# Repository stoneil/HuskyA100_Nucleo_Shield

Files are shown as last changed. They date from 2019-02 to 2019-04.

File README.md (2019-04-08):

Husky A100 Nucleo Shield
===

## Circuit

This board is for my MQP (Major Qualifying Project) to develop a autonomous robotic platform to compete in the Intelligent Ground Vehicle Competition. The purpose of this board is to provide a secure connection between the STM32F7 Nucleo microcontroller board, the Talon motor controllers (PWM) and the US Digital quadrature encoders. It breaks out power and I/O to all the connectors.

## PCB Layout
v1.0
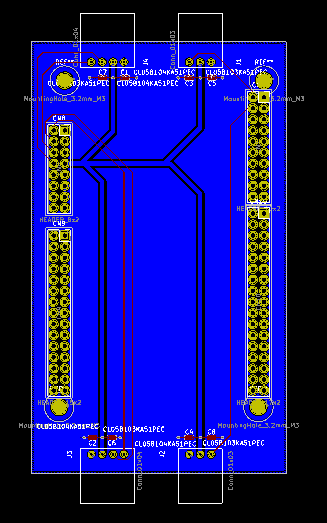
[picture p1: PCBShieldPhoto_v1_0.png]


v1.2
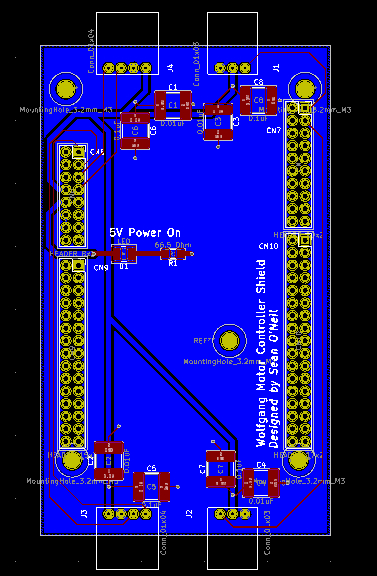
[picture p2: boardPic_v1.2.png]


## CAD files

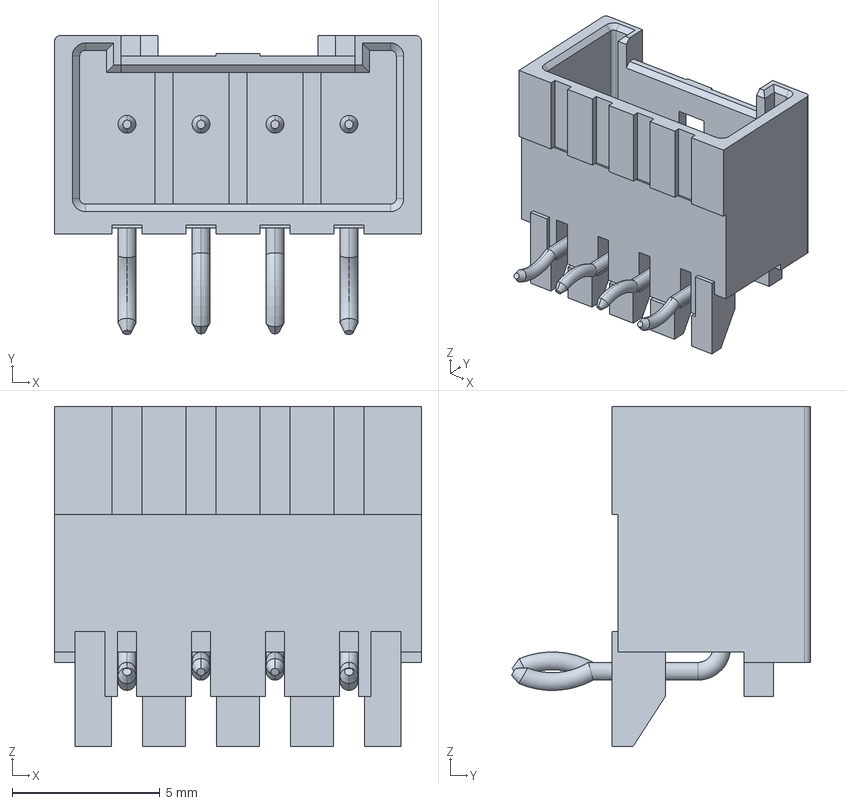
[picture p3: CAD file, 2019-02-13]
Custom_Project_Libraries/Molex_Mini-Lock.shapes/Molex Mini-Lock Horizontal Header 4 circuit.stp
12.4 x 10.1 x 11.5 mm

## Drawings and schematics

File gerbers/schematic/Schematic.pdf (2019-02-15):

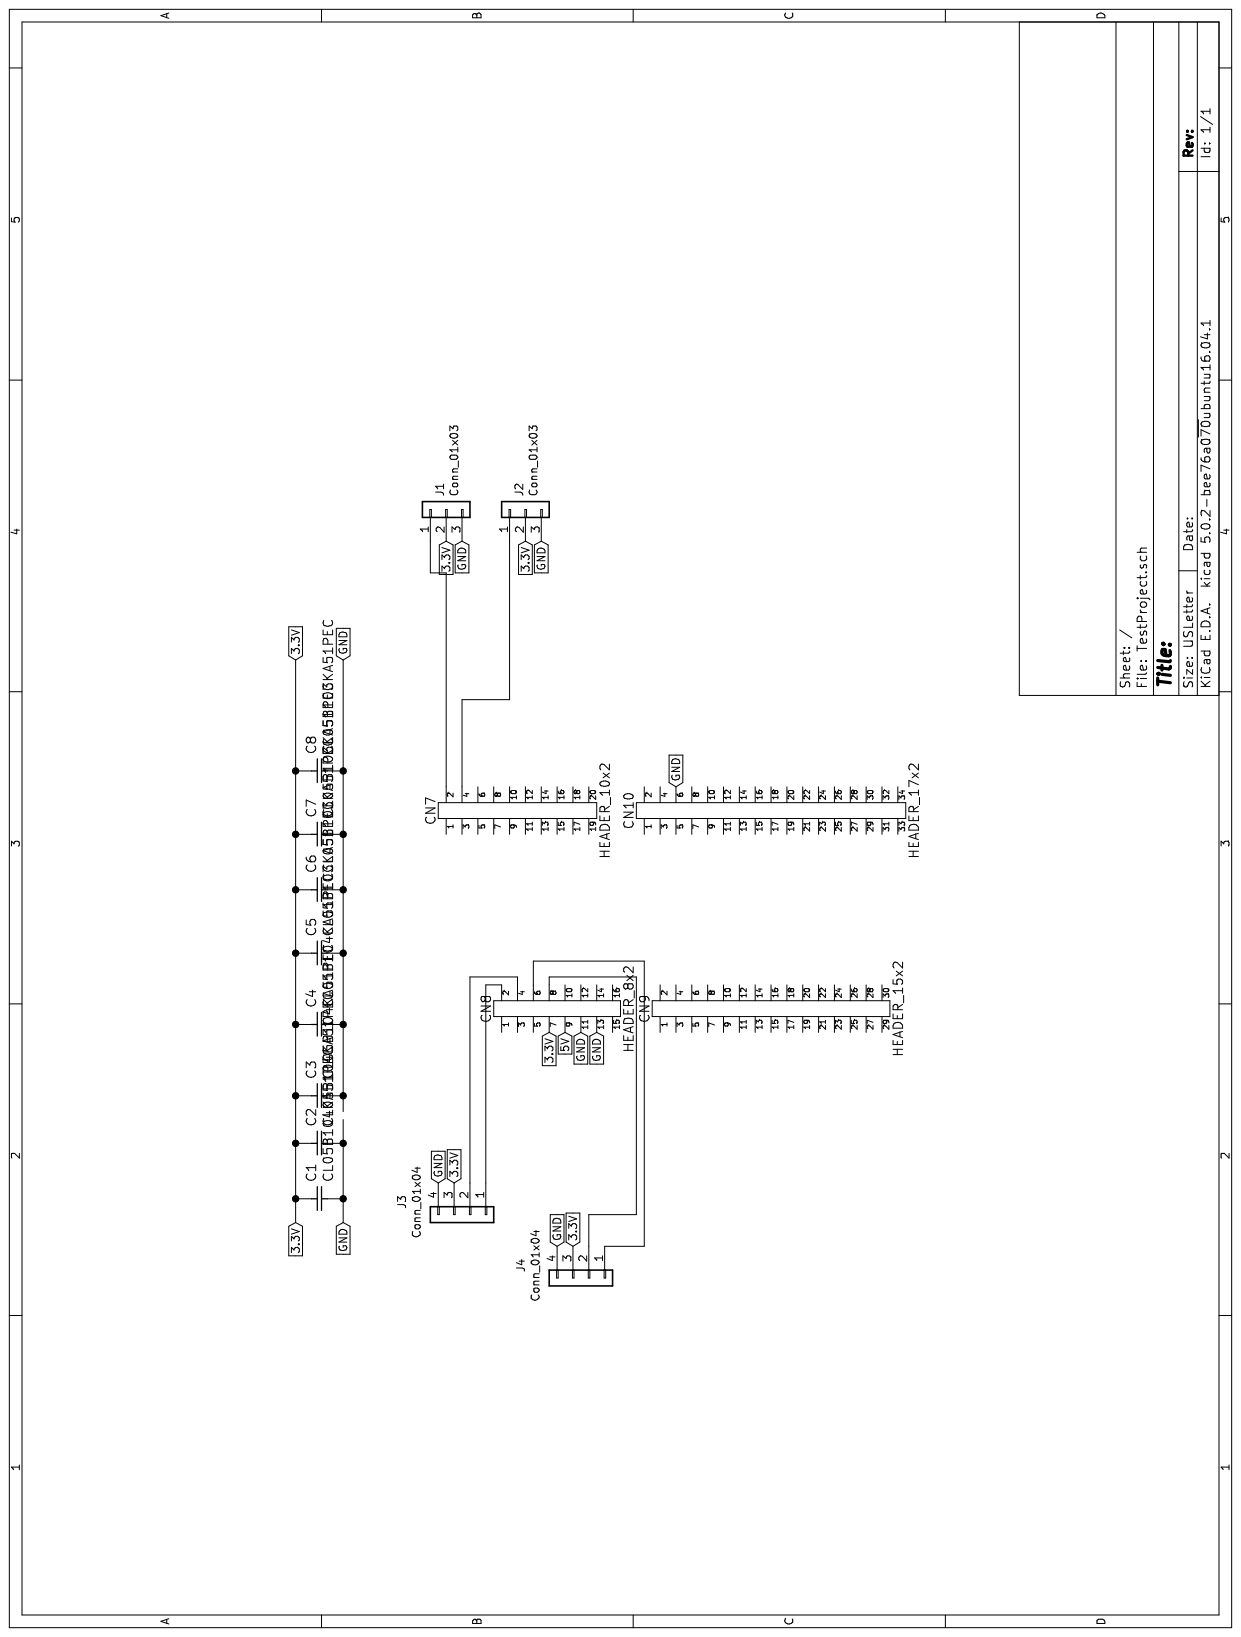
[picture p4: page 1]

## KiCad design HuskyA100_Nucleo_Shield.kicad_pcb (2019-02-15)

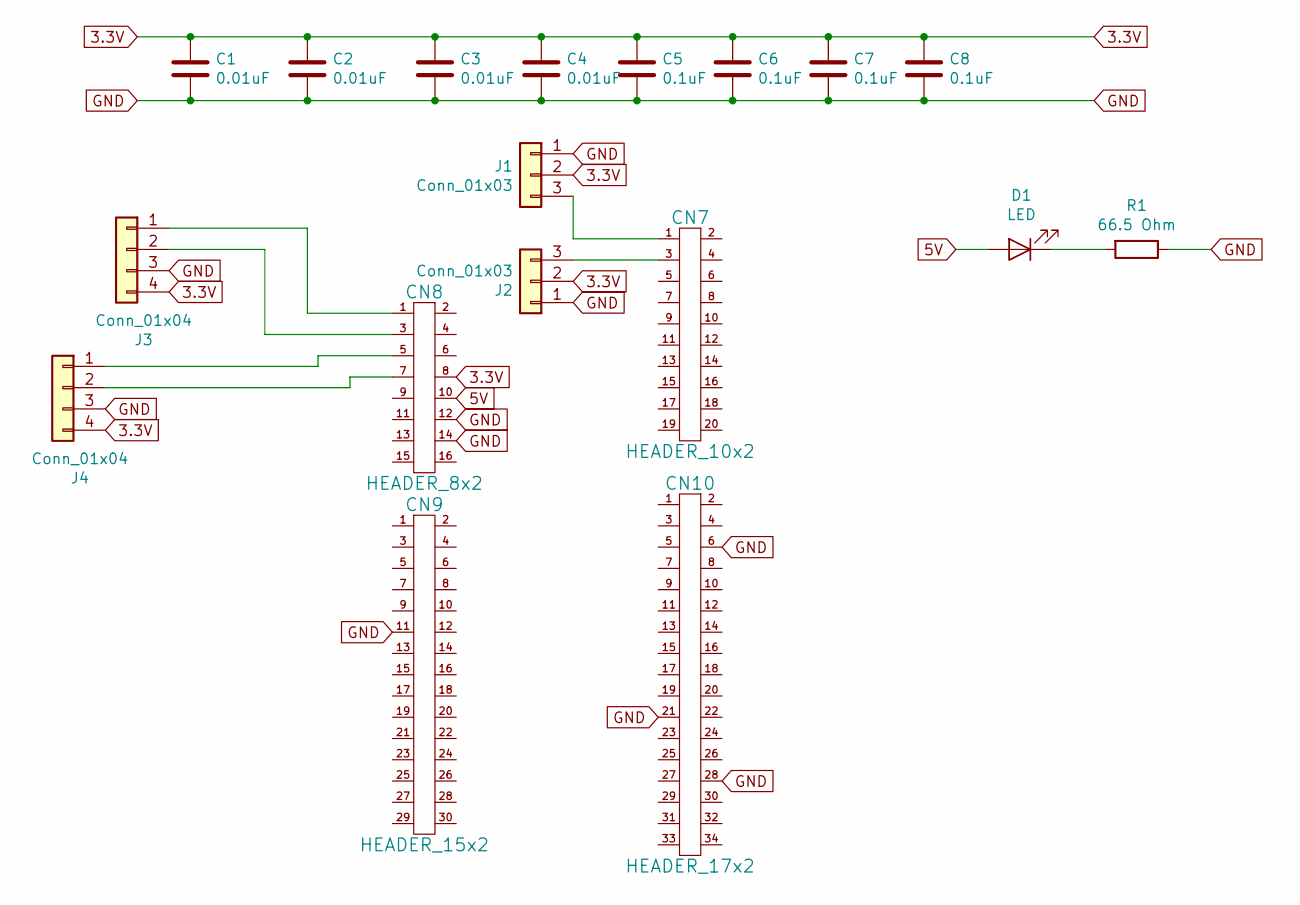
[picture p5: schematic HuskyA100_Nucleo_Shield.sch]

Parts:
C1, C2, C3, C4: 0.01uF; C_2220_5650Metric_Pad1.97x5.40mm_HandSolder
C5, C6, C7, C8: 0.1uF; C_2220_5650Metric_Pad1.97x5.40mm_HandSolder
CN7: HEADER_10x2; PinSocket_2x10_P2.54mm_Vertical
CN8: HEADER_8x2; PinSocket_2x08_P2.54mm_Vertical
CN9: HEADER_15x2; PinSocket_2x15_P2.54mm_Vertical
CN10: HEADER_17x2; PinSocket_2x17_P2.54mm_Vertical
D1: LED; LED_PLCC-2
J1, J2: Conn_01x03; Molex Mini-Lock Horizontal Header 3 circuit
J3, J4: Conn_01x04; Molex Mini-Lock Horizontal Header 4 circuit
R1: 66.5 Ohm; R_1206_3216Metric_Pad1.42x1.75mm_HandSolder

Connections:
3.3V: C1.1, C2.1, C3.1, C4.1, C5.1, C6.1, C7.1, C8.1, CN8.8, J1.2, J2.2, J3.4, J4.4
5V: CN8.10, D1.2 (A)
GND: C1.2, C2.2, C3.2, C4.2, C5.2, C6.2, C7.2, C8.2, CN8.12, CN8.14, CN9.11, CN10.6, CN10.21, CN10.28, J1.1, J2.1, J3.3, J4.3, R1.1
unnamed: CN7.1, J1.3
unnamed: CN7.3, J2.3
unnamed: CN8.1, J3.1
unnamed: CN8.3, J3.2
unnamed: CN8.5, J4.1
unnamed: CN8.7, J4.2
unnamed: D1.1 (K), R1.2

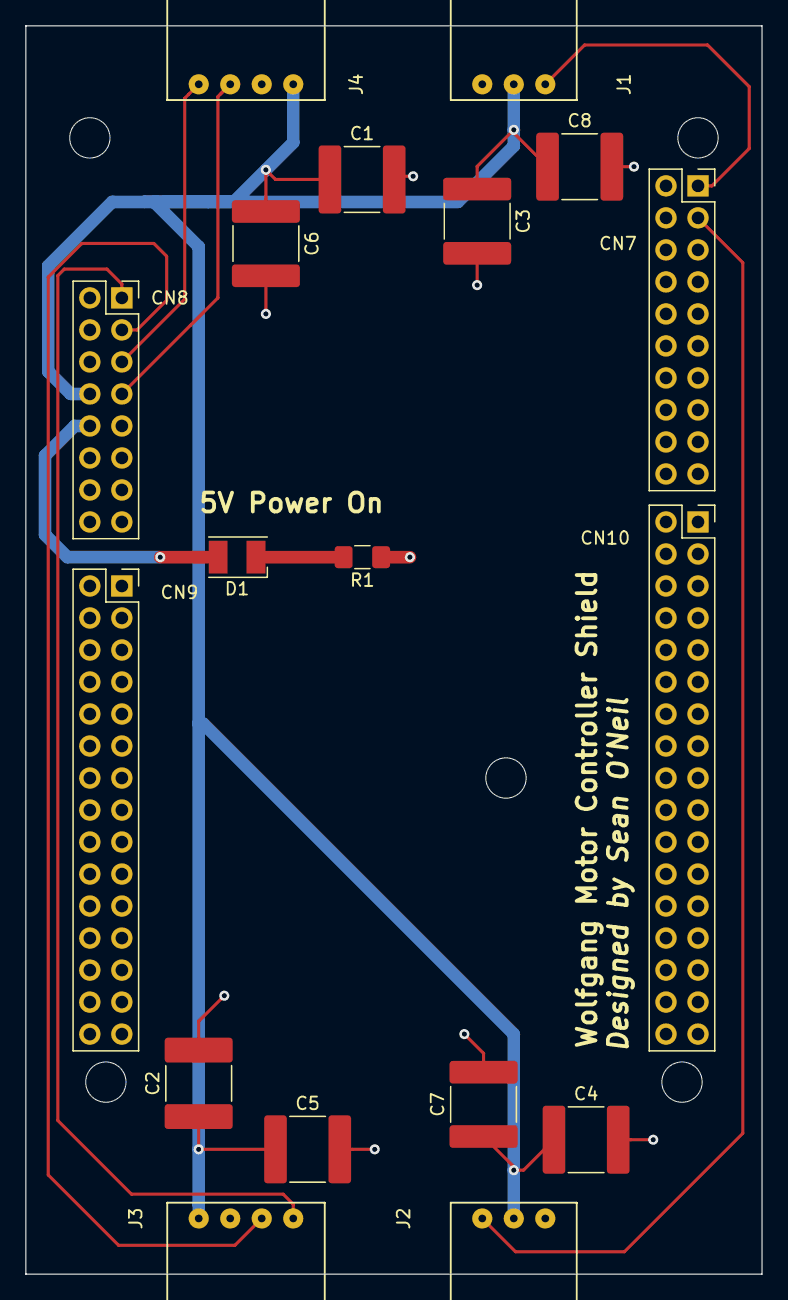
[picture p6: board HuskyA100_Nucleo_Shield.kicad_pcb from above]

Board: 2 copper layers, 58.4 x 99.1 mm, 18 parts (0 on the bottom side), 10 nets.

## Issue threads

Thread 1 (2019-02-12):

Fix header connector spacing, unflip the header connections, fix through hole locations, and enlargen annular rings on Molex connector pads

stoneil, 2019-02-12:

Closed 2019-02-13.

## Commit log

2019-02-10 committing the first printed board version of the design and added a README
    [HuskyA100_Nucleo_Shield.kicad_pcb, HuskyA100_Nucleo_Shield.sch]
2019-02-13 rerouted the pins to be correct in the schematic + deleted old traces
    [HuskyA100_Nucleo_Shield.kicad_pcb, HuskyA100_Nucleo_Shield.sch]
2019-02-13 fixed header connector spacing and mounting hole placement
    [HuskyA100_Nucleo_Shield.kicad_pcb]
2019-02-13 Fixed #1 - enlargened Molex Connector pads for easier soldering. Last commit for this Issue
    [HuskyA100_Nucleo_Shield.kicad_pcb]
2019-02-13 Fixed #2 brought custom libraries I've been using into project repo and changed the symbol and footprint table URIs accordingly
    [Molex Mini-Lock Horizontal Header 4 circuit.stp]
2019-02-14 routed the traces
    [HuskyA100_Nucleo_Shield.kicad_pcb]
2019-02-15 Fixed #3 - replaced bypass caps with 5.6mm x 5.0mm case size to make them more easiy solderable
    [HuskyA100_Nucleo_Shield.kicad_pcb, HuskyA100_Nucleo_Shield.sch]
2019-02-15 Fix #4 - added power led and authorship. Also made the capacitor pads to 'hand-solderable' for easier assembly
    [HuskyA100_Nucleo_Shield.kicad_pcb, HuskyA100_Nucleo_Shield.sch]
2019-02-15 added a title, miscellaneous fixes changes
    [HuskyA100_Nucleo_Shield.kicad_pcb, HuskyA100_Nucleo_Shield.sch]
2019-02-15 plotted the gerbers for V2 and added soldermask clearance from DFM suggestions
    [HuskyA100_Nucleo_Shield-B.Cu.gbr, HuskyA100_Nucleo_Shield-B.Mask.gbr, HuskyA100_Nucleo_Shield-B.Paste.gbr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]
2019-02-27 added gerbers that were sent for rev2
    [HuskyA100_Nucleo_Shield-B.Cu.gbr, HuskyA100_Nucleo_Shield-B.Mask.gbr, HuskyA100_Nucleo_Shield-B.Paste.gbr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]
